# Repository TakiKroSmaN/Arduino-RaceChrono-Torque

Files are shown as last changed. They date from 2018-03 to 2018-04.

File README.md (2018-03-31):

# Arduino-Race-Chrono-Torque
Rece Chrono or Torque for cars without OBD II

This is my datalogger for car without OBD II in my case Honda Civic B16A2
You can connect with RaceChrono or Torque application using a buetooth HC-05 or HC-06.
I used Arduino Pro Micro.
In RaceChrono there is no, or I don't know how to create new sensor so I used water temp as gear pos and intake temp as VTEC indicator etc.
In Torque it's shows under correct names.
Base for Torque I have found here: https://torque-bhp.com/wiki/Arduino

there are some bugs for sure but in my car is working good enoght

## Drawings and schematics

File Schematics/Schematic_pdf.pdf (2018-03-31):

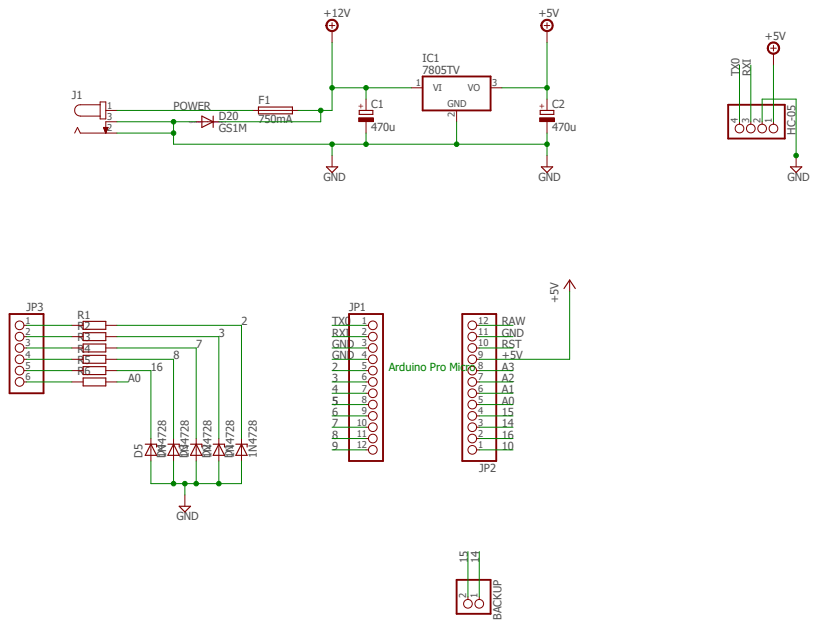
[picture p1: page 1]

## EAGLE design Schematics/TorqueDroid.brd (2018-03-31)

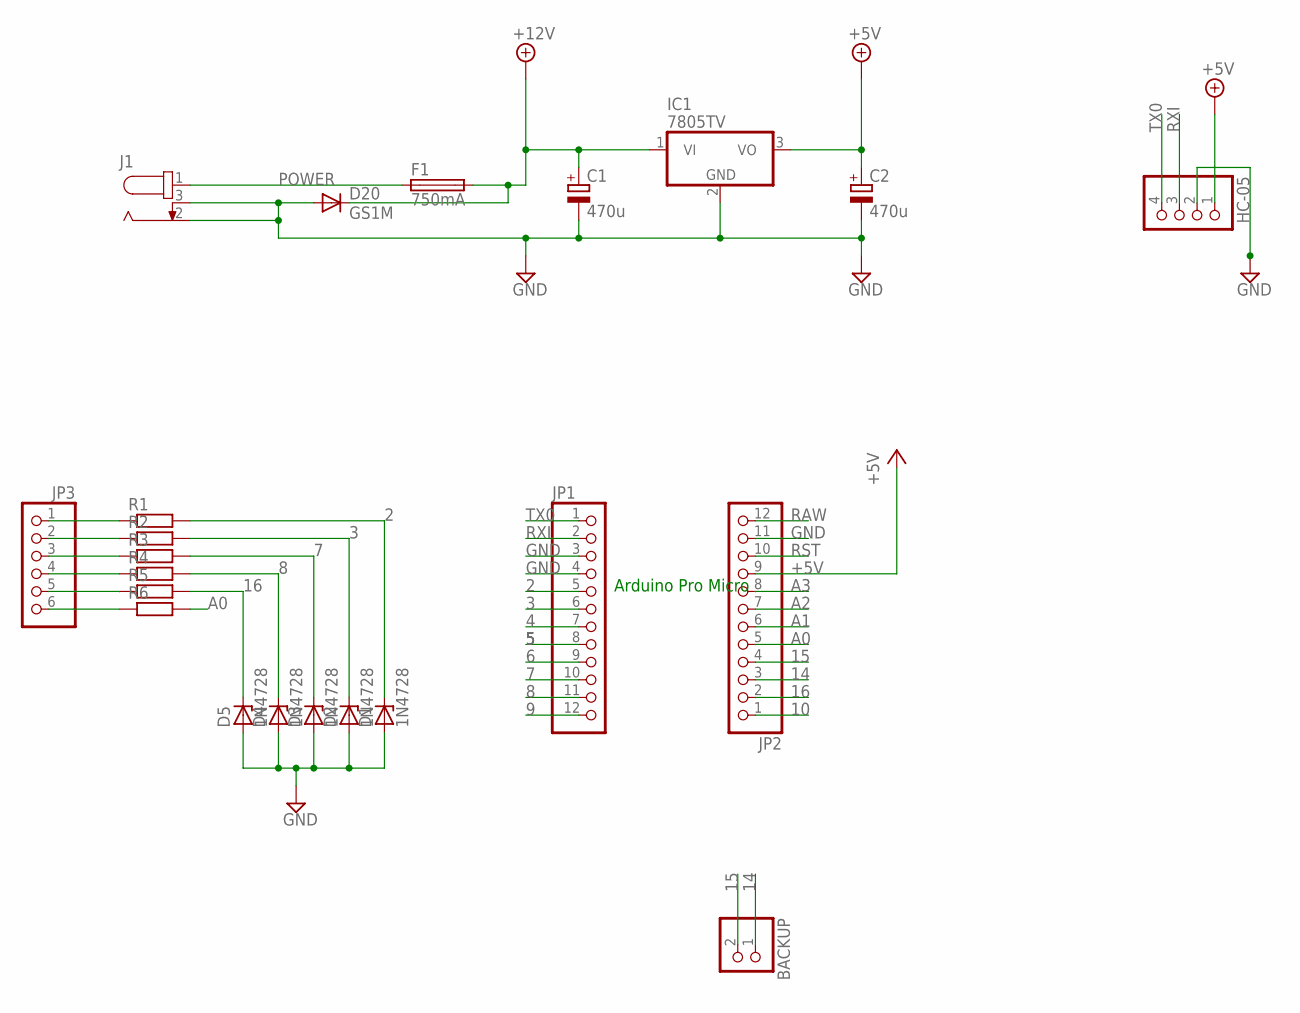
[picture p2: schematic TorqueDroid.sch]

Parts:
BACKUP: PINHD-1X2; 1X02
C1, C2: 470u; E3,5-10
D1, D2, D3, D4, D5: 1N4728; DO41Z10
D20: GS1M; SMA
F1: 750mA; MF-SMDF050
HC-05: PINHD-1X4; 1X04
IC1: 7805TV; TO220V
J1: 694102303002; 69410X303002
JP1, JP2: PINHD-1X12; 1X12
JP3: PINHD-1X6/90; 1X06/90
R1, R2, R3, R4, R5, R6: R-EU_R0805; R0805

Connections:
2: D1.C, JP1.5, R1.2
3: D2.C, JP1.6, R2.2
4: JP1.7
5: JP1.8
6: JP1.9
7: D3.C, JP1.10, R3.2
8: D4.C, JP1.11, R4.2
9: JP1.12
10: JP2.1
14: BACKUP.1, JP2.3; also elsewhere on the board
15: BACKUP.2, JP2.4; also elsewhere on the board
16: D5.C, JP2.2, R5.2
+5V: C2.+, HC-05.1, IC1.3 (VO), JP2.9; also elsewhere on the board
+9V: C1.+, D20.C, F1.2, IC1.1 (VI)
A0: JP2.5, R6.2
A1: JP2.6
A2: JP2.7
A3: JP2.8
GND: C1.-, C2.-, D1.A, D2.A, D3.A, D4.A, D5.A, D20.A, HC-05.2, IC1.2 (GND), J1.2, J1.3, JP1.3, JP1.4, JP2.11; also elsewhere on the board
unnamed: JP3.1, R1.1
unnamed: JP3.2, R2.1
unnamed: JP3.3, R3.1
unnamed: JP3.4, R4.1
unnamed: JP3.5, R5.1
unnamed: JP3.6, R6.1
POWER: F1.1, J1.1
RAW: JP2.12
RST: JP2.10
RXI: HC-05.3, JP1.2; also elsewhere on the board
TX0: HC-05.4, JP1.1; also elsewhere on the board

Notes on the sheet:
Arduino Pro Micro

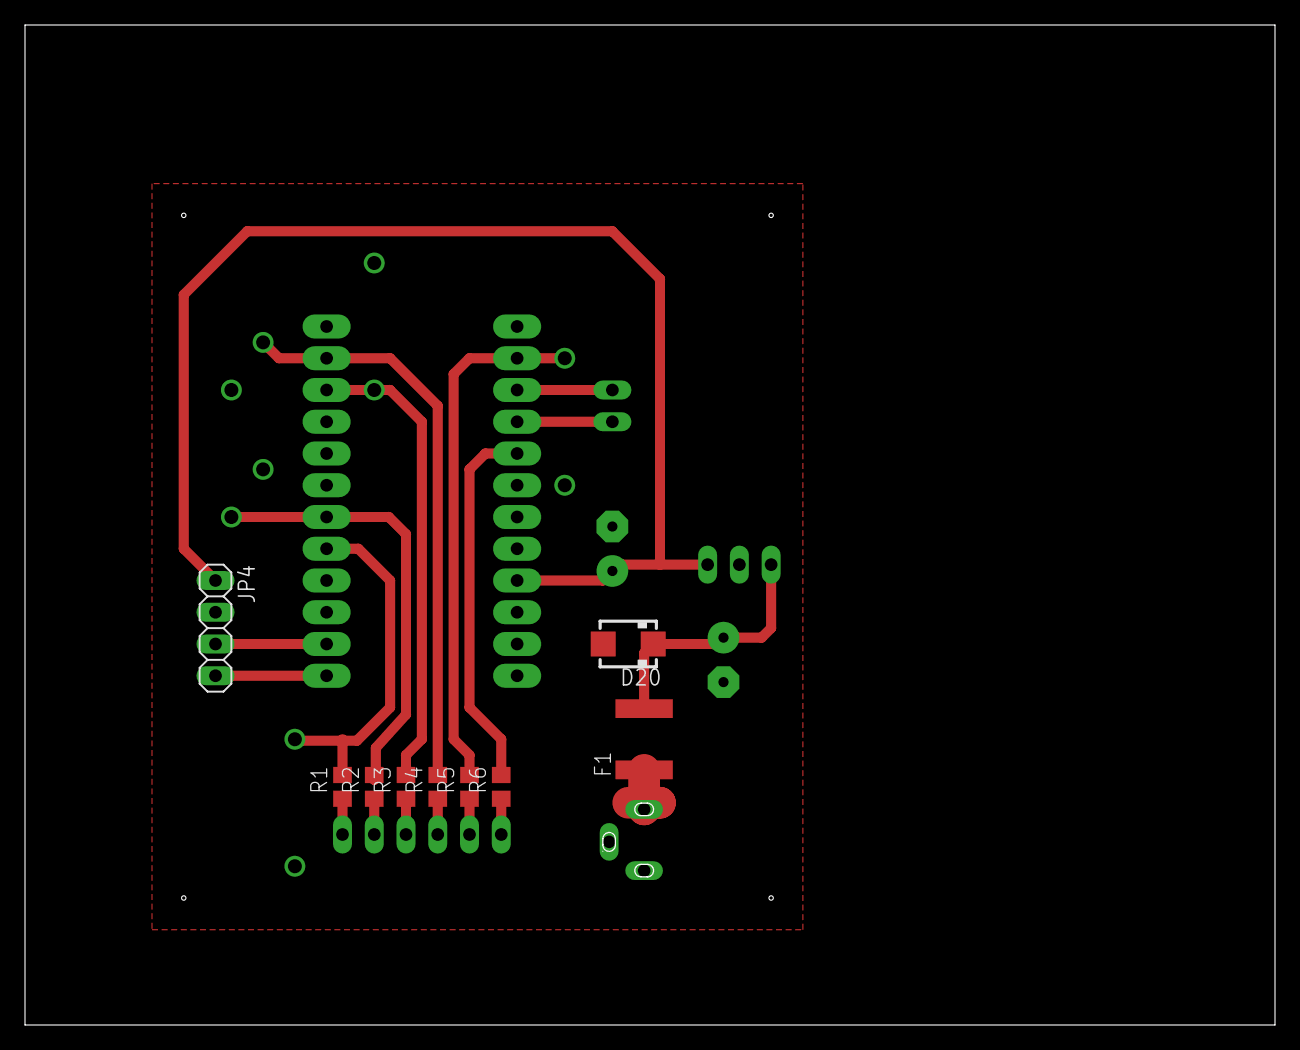
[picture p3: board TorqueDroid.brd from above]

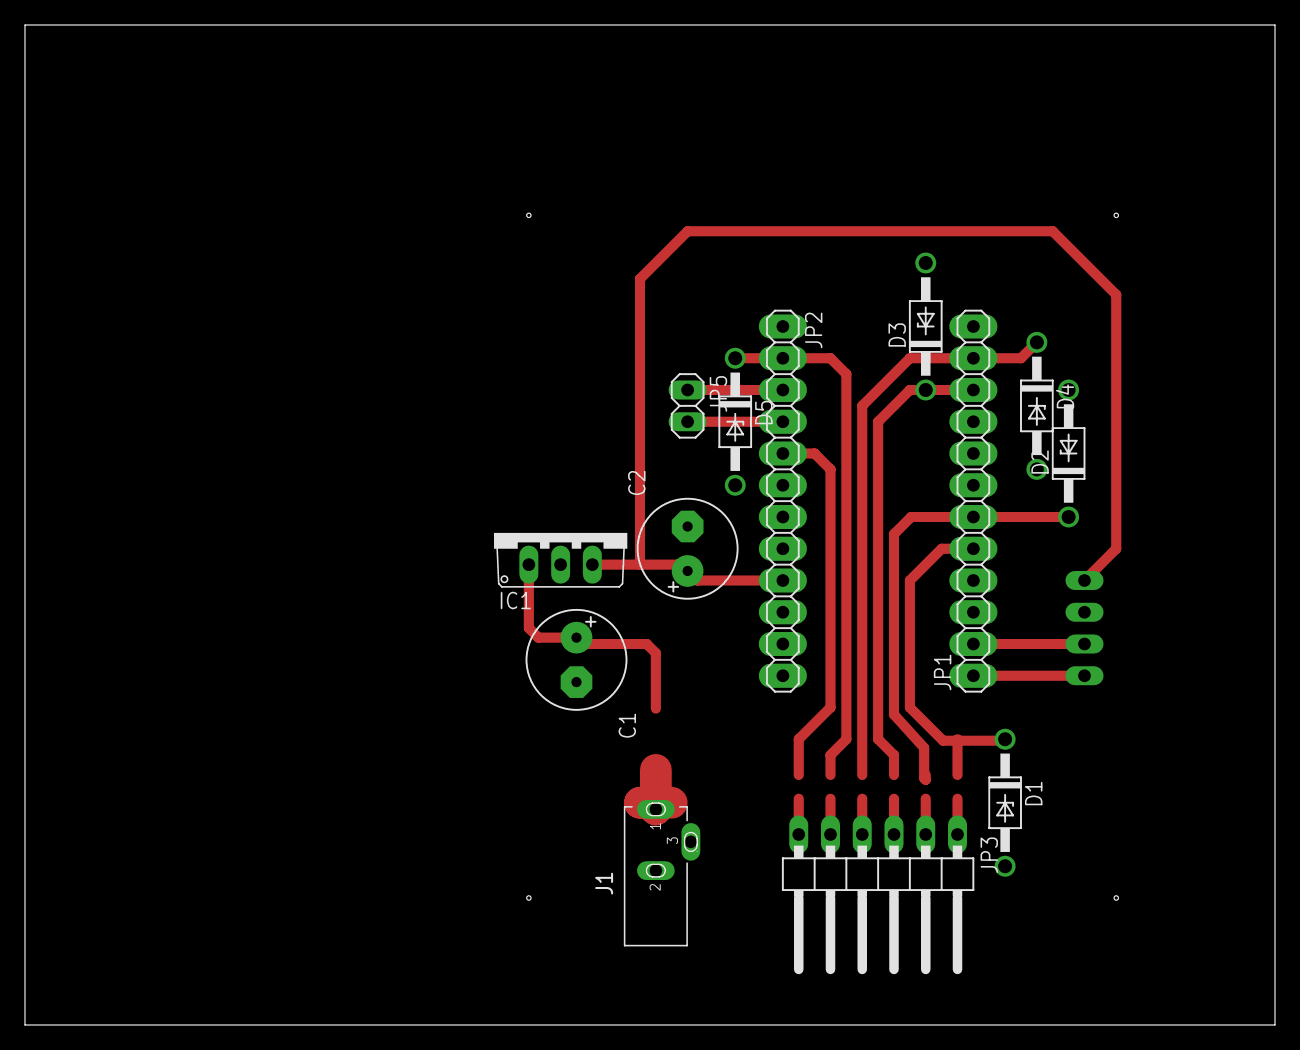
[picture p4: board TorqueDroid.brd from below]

Board: 2 copper layers, 100.0 x 80.0 mm, 22 parts (13 on the bottom side), 20 nets.

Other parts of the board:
JP4: 1X04
JP5: 1X02

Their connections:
14: JP5.1; also elsewhere on the board
15: JP5.2; also elsewhere on the board
+5V: JP4.1; also elsewhere on the board
GND: JP4.2; also elsewhere on the board
RXI: JP4.3; also elsewhere on the board
TX0: JP4.4; also elsewhere on the board

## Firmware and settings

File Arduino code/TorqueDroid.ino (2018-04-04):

#include <String.h>

// #define DEBUG  // zakomentować w gotowym projekcie
#define BT Serial1


// Various constants.
const String ATE = "ATE"; // Echo off/on
const String ATI = "ATI"; // Version id
const String ATZ = "ATZ"; // Reset
const String ATS = "ATS"; // Set protocol X
const String ATH = "ATH"; // Headers off / on
const String ATL = "ATL"; // Linefeeds off/on
const String ATM = "ATM"; // Memory off/on
const String GETDEFINITIONS = "GETDEFINITIONS"; // Get sensor definitions
const String GETCONFIGURATION = "GETCONFIGURATION"; // Get config of app (hide car sensors, devices sensors, etc)
const String GETSENSORS = "G"; // Get sensor values, one shot.
const String SETSENSOR = "S"; // Set a sensor value
const String PROMPT = ">";
const String CANBUS = "6"; // canbus 500k 11 bit protocol id for elm.
const String ATDPN = "ATDPN";
const String ATDESC = "AT@1";
const String ATAT = "ATAT";
const String LF = "\n";
const String VERSION = "Torque Protocol Interface v0.0.1"; // Don't change this - it's used by Torque so it knows what interface it is connected to
const String VERSION_DESC = "Tomasz Kroczak Racing :)";
const String OK = "OK";
const String ANALOG = "a";
const String DIGITAL = "d";
const String IS_INPUT = "i";
const String IS_OUTPUT = "o";

const String INI0 = "0100";
const String INI2 = "0120";
const String INI4 = "0140";
const String INI6 = "0160";
const String INI8 = "0180";
const String RPM = "010C";
const String PREDKOSC = "010D";
const String THROTTLE = "0111";
const String BRAKE = "0113"; // brake as oxygen sensor
const String GEAR = "010F"; // gear as Intake temp
const String VTEC = "0105"; // gear as cooland temp

String fromTorque = "";

// *********************************************************************
//                definicje pinów
// *********************************************************************
#define SpeedSensor            2
#define ShaftSensor            3
#define clutch                 7
#define brakePin               8
#define VTECPin               16
#define ThrottlePin           A0

// *********************************************************************
//                aliasowanie stałych wartości
// *********************************************************************
#define iloscPomiarow 10

// współczynniki po podzieleniu obrotów przez prędkość
#define tolgear    5
#define wspgear1 163
#define wspgear2 100
#define wspgear3  71
#define wspgear4  53
#define wspgear5  43

// *********************************************************************
//                        globalne zmienne
// *********************************************************************
boolean brake;
volatile unsigned long speed = 0, rpm = 0;
volatile byte minThrottlePos = 255, impulsSpeedCounter;
byte gear = 0, throttlePos = 0;

float gearRatio[6] = {
  5.5,        // FD
  3.23,       // 1 bieg
  2.105,      // 2 bieg
  1.458,      // 3 bieg
  1.034,      // 4 bieg
  0.848,      // 5 bieg
};





// *********************************************************************
//                definicje czujników
// *********************************************************************
/**
   Array of sensors we will advertise to Torque so it can automatically import them. Using strings
   Stucture is:

    Arduino Pin, Arduino pin type, Input/Ouput, Default value(if output), ShortName, Long name, units, minimum value, maximum value

    Caveats:  Don't use a '>' in any of the names,
              Update 'sensorsSize' with the number of elements.
              Analog outputs are PWM on digital pins.

*/
const int SENSORSSIZE = 9 * 6; // each line is 9 attributes, and we have 3 lines.
const String sensors[SENSORSSIZE] = {
  "0", ANALOG,   IS_INPUT,    "0",   "VSS",      "Speed",       "km/h",    "0", "200",
  "1", ANALOG,   IS_INPUT,    "0",   "Revs",     "Revs",        "rpm",     "0", "9000",
  "2", ANALOG,   IS_INPUT,    "0",   "Throttle", "TPS",         "%",       "0", "100",
  "3", ANALOG,   IS_INPUT,    "0",   "Gear",     "GearPos",     " ",       "0", "6",
  "8", DIGITAL,  IS_INPUT,    "0",   "Brake",    "Brake",       "bit",     "0", "1",
  "13", DIGITAL,  IS_INPUT,    "0",   "VTEC",     "VTEC",        "bit",     "0", "1"
};
/**
   Configuration directives for the app to hide various things. Comma separated. Remove to enable visibility in Torque
    - handy if your project isn't car related or you want to make sensor selections relatively easy.

    Supported types:
      NO_CAR_SENSORS  - hide any car related sensors
      NO_DEVICE_SENSORS - hide any device (phone) sensors

*/
const String CONFIGURATION = "";


// *********************************************************************
//                                SETUP
// *********************************************************************
void setup() {
  //  display.begin(SSD1306_SWITCHCAPVCC, 0x3C);  // initialize with the I2C addr 0x3D (for the 128x64)
  BT.begin(115200);  // BT.connenct

#ifdef DEBUG
  Serial.begin(115200);
  Serial.println("Setup Start");
#endif
#ifndef DEBUG
  delay(3000);
#endif
  // Init the pins
  initSensors();

  pinMode(SpeedSensor, INPUT);
  pinMode(ShaftSensor, INPUT);
  pinMode(clutch, INPUT);
  pinMode(brakePin, INPUT);
  pinMode(VTECPin, INPUT);
  pinMode(ThrottlePin, INPUT);

  attachInterrupt(digitalPinToInterrupt(SpeedSensor), speedRead, RISING);             //call interrupt #2 when the tach input goes high
  attachInterrupt(digitalPinToInterrupt(ShaftSensor), rpmRead, RISING);             //call interrupt #3 when the tach input goes high
}




// *********************************************************************
//                                LOOP
// *********************************************************************
void loop() {

  if (BT.available()) {
    char c = BT.read();
    if ((c == '\n' || c == '\r') && fromTorque.length() > 0) {
      fromTorque.toUpperCase();
      processCommand(fromTorque);
      fromTorque = "";
    } else if (c != ' ' && c != '\n' && c != '\r') {
      // Ignore spaces.
      fromTorque += c;
    }
  }
}

/**
   Parse the commands sent from Torque
*/
void processCommand(String command) {
#ifdef DEBUG
  // Debug - see what torque is sending on your serial monitor
  //Serial.println(command);
#endif

  // Simple command processing from the app to the arduino..
  if (command.equals(ATZ)) {
    initSensors(); // reset the pins
    BT.print(VERSION);
    BT.print(LF);
    BT.print(OK);
  } else if (command.startsWith(ATE)) {
    BT.print(OK);
  } else if (command.startsWith(ATI)) {
    BT.print(VERSION);
    BT.print(LF);
    BT.print(OK);
  } else if (command.startsWith(ATDESC)) {
    BT.print(VERSION_DESC);
    BT.print(LF);
    BT.print(OK);
  } else if (command.startsWith(ATL)) {
    BT.print(OK);
  } else if (command.startsWith(ATAT)) {
    BT.print(OK);
  } else if (command.startsWith(ATH)) {
    BT.print(OK);
  } else if (command.startsWith(ATM)) {
    BT.print(OK);
  } else if (command.startsWith(ATS)) {
    // Set protocol
    BT.print(OK);
  } else if (command.startsWith(ATDPN)) {
    BT.print(CANBUS);
  } else if (command.startsWith(GETDEFINITIONS)) {
    showSensorDefinitions();
  } else if (command.startsWith(GETSENSORS)) {
    getSensorValues();
  } else if (command.startsWith(GETCONFIGURATION)) {
    getConfiguration();
  } else if (command.startsWith(SETSENSOR)) {
    setSensorValue(command);
  }
  else if (command.startsWith(INI0)) {
    BT.print("41 00 98 3B A0 13");
  }
  else if (command.startsWith(INI2)) {
    BT.print("41 20 B8 01 A0 01");
  }
  else if (command.startsWith(INI4)) {
    BT.print("41 40 CC D2 00 01");
  }
  else if (command.startsWith(INI6)) {
    BT.print("41 60 02 80 03 01");
  }
  else if (command.startsWith(INI8)) {
    BT.print("41 80 00 20 00 00");
  }
  else if (command.startsWith(RPM)) {
    BT.print(RPM);
    BT.print("41 0C ");
    BT.print(IntNaChar(rpm * 4, 'H'), HEX);
    BT.print(" ");
    BT.print(IntNaChar(rpm * 4, 'L'), HEX);
  }
  else if (command.startsWith(PREDKOSC)) {
    BT.print(PREDKOSC);
    BT.print("41 0D " + String(speed, HEX));
  }
  else if (command.startsWith(THROTTLE)) {
    readThrottleBrake();
    BT.print(THROTTLE);
    BT.print("41 11 " + String((throttlePos * 255) / 100, HEX));
  }

  else if (command.startsWith(BRAKE)) {
    readThrottleBrake();
    BT.print(BRAKE);
    BT.print("41 13 " + String(brake, HEX));
  }

  else if (command.startsWith(GEAR)) {
    gearRead();
    BT.print(GEAR);
    BT.print("41 0F " + String(gear + 40, HEX));
  }

  else if (command.startsWith(VTEC)) {
    BT.print(VTEC);
    BT.print("41 05 " + String(digitalRead(VTECPin) + 40, HEX));
  }

  BT.print(LF);
  BT.print(PROMPT);
}

/**
   List all the sensors to the app
*/
void showSensorDefinitions() {
  int id = 0;
  for (int i = 0; i < SENSORSSIZE / 9; i++) {
    for (int j = 0; j < 9; j++) {
      id = (i * 9) + j;
      BT.print(sensors[id]);

      if (id + 1 < SENSORSSIZE) {
        BT.print(',');
      }
    }
    BT.print(LF);
  }
}

/**
   Dump sensor information for input sensors.

   Format to Torque is id:type:value
*/
void getSensorValues() {
  noInterrupts();
  // speed = random(0, 200);
  // rpm = random(0, 9000);
  //gear = random(0, 5);
  //throttlePos = random(0, 100);

  readThrottleBrake();
  gearRead();

  for (int i = 0; i < SENSORSSIZE / 9; i++) {
    int group = i * 9;
    int id = sensors[group].toInt();
    String type = sensors[group + 1];
    boolean isOutput = sensors[group + 2].equals(IS_OUTPUT);

#ifdef DEBUG
    /*    Serial.println(SENSORSSIZE);
        Serial.println(group);
        Serial.println(id);
        Serial.println("**********************");*/
#endif
    // ****************************
    // Speed
    // ****************************
    if (!isOutput) {
      if (id == 0) {
        BT.print(id);
        BT.print(":");
        BT.print(type);
        BT.print(":");
        if (type.equals(ANALOG)) {
          //    Serial.print("speed = ");
          //    Serial.println(speed);
          BT.print(speed);
        } else if (type.equals(DIGITAL)) {
          BT.print(digitalRead(id));
        }
        BT.print('\n');
      }
    }

    // ****************************
    // RPM
    // ****************************
    if (!isOutput) {
      if (id == 1) {
        BT.print(id);
        BT.print(":");
        BT.print(type);
        BT.print(":");
        if (type.equals(ANALOG)) {
          //     Serial.print("rpm = ");
          //     Serial.println(rpm);
          BT.print(rpm);
        } else if (type.equals(DIGITAL)) {
          BT.print(digitalRead(id));
        }
        BT.print('\n');
      }
    }

    // ****************************
    // ThrottlePos
    // ****************************
    if (!isOutput) {
      if (id == 2) {
        BT.print(id);
        BT.print(":");
        BT.print(type);
        BT.print(":");
        if (type.equals(ANALOG)) {
          //     Serial.print("throttlePos = ");
          //     Serial.println(throttlePos);
          BT.print(throttlePos);
        } else if (type.equals(DIGITAL)) {
          BT.print(digitalRead(id));
        }
        BT.print('\n');
      }
    }

    // ****************************
    // Gear
    // ****************************
    if (!isOutput) {
      if (id == 3) {
        BT.print(id);
        BT.print(":");
        BT.print(type);
        BT.print(":");
        if (type.equals(ANALOG)) {
          Serial.print(".");//gear = ");
          //  Serial.println(gear);
          BT.print(gear);
        } else if (type.equals(DIGITAL)) {
          BT.print(digitalRead(id));
        }
        BT.print('\n');
      }
    }

    // ****************************
    // Brake
    // ****************************
    if (!isOutput) {
      if (id == 8) {
        BT.print(id);
        BT.print(":");
        BT.print(type);
        BT.print(":");
        if (type.equals(ANALOG)) {
          BT.print(analogRead(id));
        } else if (type.equals(DIGITAL)) {
          // Serial.print("Brake = ");
          // Serial.println(digitalRead(id));
          BT.print(digitalRead(id));
        }
        BT.print('\n');
      }
    }

    // ****************************
    // VTEC
    // ****************************
    if (!isOutput) {
      if (id == 13) {
        BT.print(id);
        BT.print(":");
        BT.print(type);
        BT.print(":");
        if (type.equals(ANALOG)) {
          BT.print(analogRead(id));
        } else if (type.equals(DIGITAL)) {
          BT.print(digitalRead(VTECPin));
        }
        BT.print('\n');
      }
    }

  }
  interrupts();
}

/**
   Sets a sensors value
*/
void setSensorValue(String command) {
  int index = command.indexOf(":");
  int id = command.substring(1, index).toInt();
  int value = command.substring(index + 1, command.length()).toInt();

  for (int i = 0; i < SENSORSSIZE / 9; i++) {
    int group = i * 9;
    int sid = sensors[group].toInt();
    boolean isOutput = sensors[group + 2].equals(IS_OUTPUT);
    if (isOutput) {

      if (sid == id) {

        String type = sensors[group + 1];
        if (type.equals(ANALOG)) {
          analogWrite(sid, constrain(value, 0, 255));
        } else if (type.equals(DIGITAL)) {
          digitalWrite(sid, value > 0 ? HIGH : LOW);
        }
        break;
      }
    }
  }
}

/**
    Init the sensor definitions (input/output, default output states, etc)
*/
void initSensors() {
  for (int i = 0; i < SENSORSSIZE / 9; i++) {
    int group = i * 9;
    int id = sensors[group].toInt();
    String type = sensors[group + 1];
    boolean isOutput = sensors[group + 2].equals(IS_OUTPUT);
    int defaultValue = sensors[group + 3].toInt();


    if (isOutput) {
      if (type.equals(ANALOG)) {
        pinMode(id, OUTPUT);
        analogWrite(id, constrain(defaultValue, 0, 255));
      } else if (type.equals(DIGITAL)) {
        pinMode(id, OUTPUT);
        digitalWrite(id, defaultValue > 0 ? HIGH : LOW);
      }
    }
  }
}

void getConfiguration() {
  BT.print(CONFIGURATION);
}












// *********************************************************************
//                       odczyt obrotów silnika
// *********************************************************************
void rpmRead() {
  static boolean impulsRpmCounter;
  static byte licznikDoUsrednienia;
  static unsigned int rpmSrednia[iloscPomiarow];
  static unsigned long rpmCalculation;

  noInterrupts();
  if (impulsRpmCounter == 0) {
    rpmCalculation = micros();
  }
  else if (impulsRpmCounter == 1) {
    rpmCalculation = micros() - rpmCalculation;
    rpmSrednia[licznikDoUsrednienia] = 30000000 / rpmCalculation;
    licznikDoUsrednienia++;
  }
  rpm = 0;
  for (byte i = 0; i < iloscPomiarow; i++) {
    rpm += rpmSrednia[i];
  }
  rpm /= iloscPomiarow;

  impulsRpmCounter = !impulsRpmCounter;
  if (licznikDoUsrednienia >= iloscPomiarow) licznikDoUsrednienia = 0;
  interrupts();
}



// *********************************************************************
//                          odczyt prędkości
// *********************************************************************
void speedRead() {
  static boolean impulsSpeedCounter;
  static byte licznikDoUsrednienia;
  static unsigned int speedSrednia[iloscPomiarow];
  static unsigned long speedCalculation;

  noInterrupts();
  if (impulsSpeedCounter == 0) {
    speedCalculation = micros();
  }
  else if (impulsSpeedCounter == 1) {
    speedCalculation = micros() - speedCalculation;
    speedSrednia[licznikDoUsrednienia] = 1420000 / speedCalculation;
    licznikDoUsrednienia++;
  }
  speed = 0;
  for (byte i = 0; i < iloscPomiarow; i++) {
    speed += speedSrednia[i];
  }

  speed /= iloscPomiarow;
  if (speed < 5) {
    speed = 0;
  }

  impulsSpeedCounter = !impulsSpeedCounter;
  if (licznikDoUsrednienia >= iloscPomiarow) licznikDoUsrednienia = 0;
  interrupts();
}

// *********************************************************************
//        odczyt aktualnego biegu na podstawie rpm i prędkości
// *********************************************************************
void gearRead() {
  // wynaczenie na którym biegu jedzie auto
  gear = rpm / speed;

#ifdef DEBUG
  //  Serial.print ("rpm / speed = ");
  //  Serial.println (gear);
#endif

  if      (gear >= wspgear1 - tolgear && gear <= wspgear1 + tolgear) gear = 1;
  else if (gear >= wspgear2 - tolgear && gear <= wspgear2 + tolgear) gear = 2;
  else if (gear >= wspgear3 - tolgear && gear <= wspgear3 + tolgear) gear = 3;
  else if (gear >= wspgear4 - tolgear && gear <= wspgear4 + tolgear) gear = 4;
  else if (gear >= wspgear5 - tolgear && gear <= wspgear5 + tolgear) gear = 5;
  else gear = 0;

#ifdef DEBUG
  //  Serial.print ("gear = ");
  //  Serial.println (gear);
#endif
}

// *********************************************************************
//                 Odczyt pozycji przepustnicy
// *********************************************************************
void readThrottleBrake() {
  if (analogRead(ThrottlePin) < minThrottlePos) {
    minThrottlePos = analogRead(ThrottlePin) - 2;
  }
  throttlePos = map(analogRead(ThrottlePin), minThrottlePos, 1023, 0, 100);

  brake = digitalRead(brakePin);
#ifdef DEBUG
  Serial.print ("AnalogRead Throttle = ");  Serial.println (analogRead(ThrottlePin));
  Serial.print ("throttlePos = ");  Serial.print (throttlePos);  Serial.println ("%");
  Serial.print ("brake = ");  Serial.println (brake);
#endif
}


// *********************************************************************
//                  Konversja zmiennej na High i Low bajt
// *********************************************************************

uint8_t IntNaChar(uint16_t liczba, uint8_t ktory_bajt) {
  if (ktory_bajt == 'L') {
    return (liczba & 0xFF); //Zwracamy młodszy bajt
  } else if (ktory_bajt == 'H') {
    return (liczba >> 8); //Zwracamy starszy bajt
  }
  return 1;
}

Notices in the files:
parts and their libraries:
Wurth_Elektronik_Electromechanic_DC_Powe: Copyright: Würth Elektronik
